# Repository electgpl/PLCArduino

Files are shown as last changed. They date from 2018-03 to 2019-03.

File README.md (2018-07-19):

# PLC Arduino NANO v1 

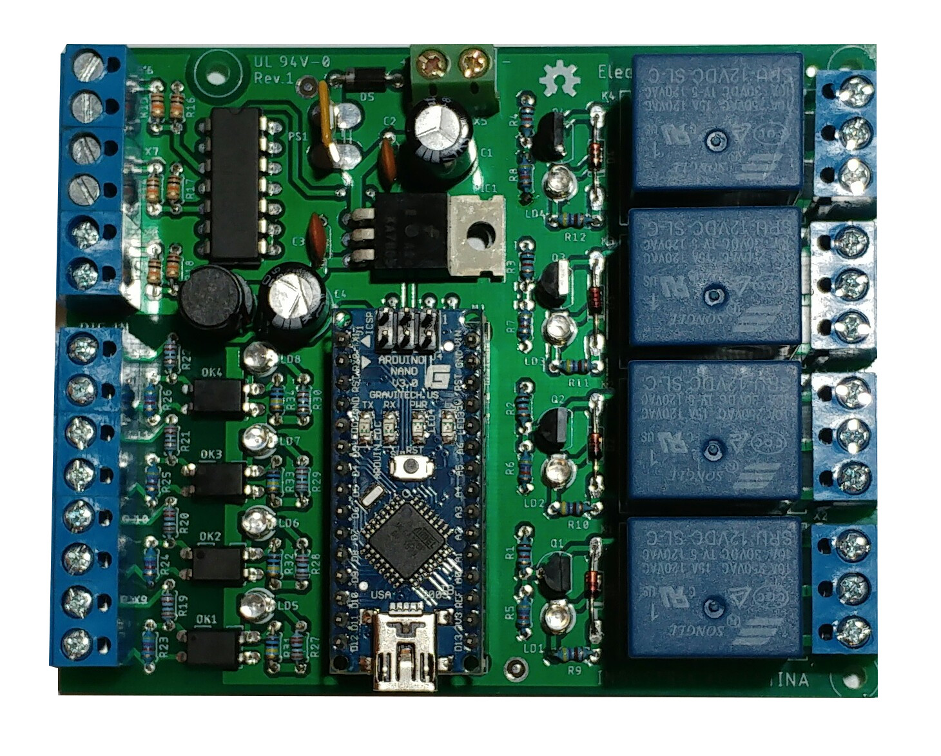
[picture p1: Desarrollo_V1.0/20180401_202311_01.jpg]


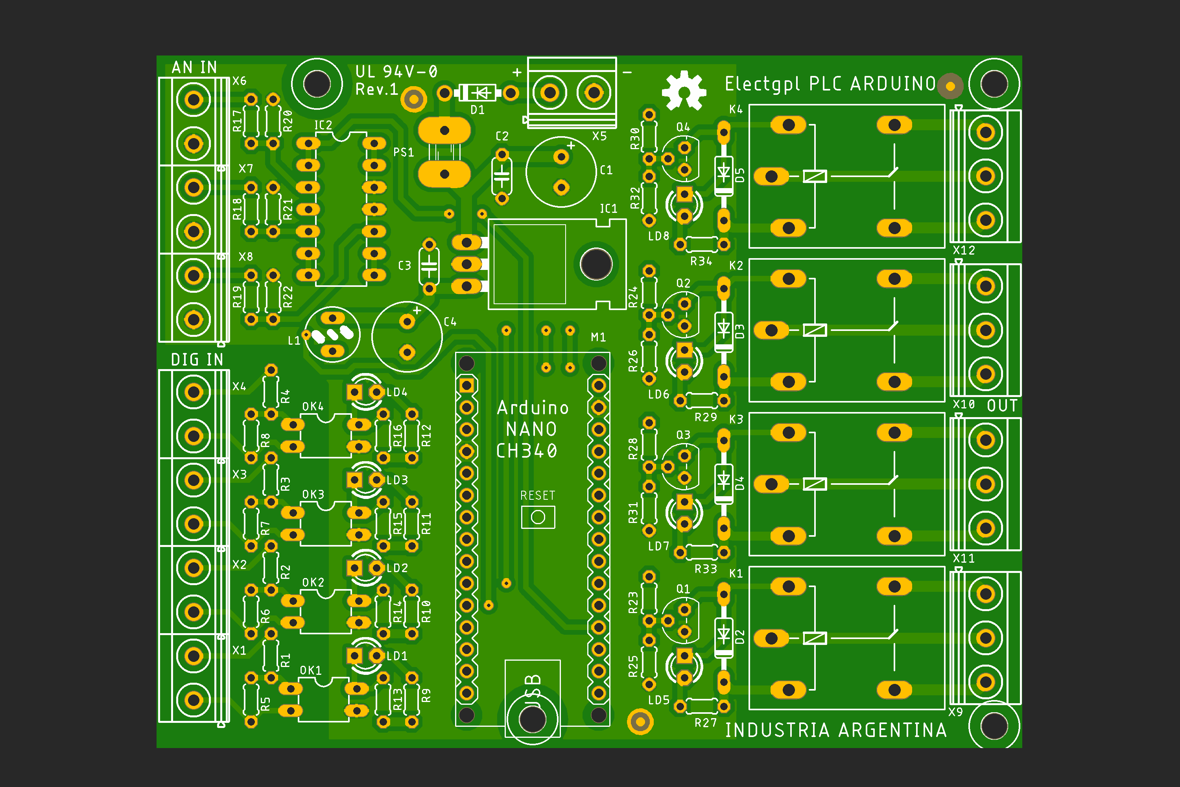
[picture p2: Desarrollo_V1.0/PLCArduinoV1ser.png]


Este es un PLC de openHard diseñado en base al microcontrolador AVR linea MEGA compatible ArduinoIDE y ArduinoNANO

  - Core AVR - **ARDUINO NANO (Versión CH340)**
  - Bootloader UART Arduino Compatible
  - USB Programming firmware
  - USB Serial Terminal/Debug
  - 4 Salidas contacto seco doble inversora 12Vdc 24Vdc 220Vac
  - 4 Entradas Digitales optoacopladas 0-10V 0-12V 0-24V 
  - 3 Entradas Analógicas Aisladas de 0-10V
  - Fuente de alimentación integrada

## Lenguajes Compatibles

  - C
  - C++
  - Basic
  - Ensamblador
  - Ladder
  - y mas...
  
## Diseño y Desarrollo

> Diseñado en dos capas con componentes THT para facilitar
> la integración al alumno, el desarrollo del PCB en el hogar y mantener
> el menor costo posible.
>                           
> PCB creado en [PCBWay].
> Diseño realizado en [Eagle].

### Instalación

Todos los archivos se encuentran disponibles en este repositorio, diagramas, pcb, etc...

### Pendientes

 - Migración del hardware AVR MEGA Compatible.
 - Incorporación de nuevos puertos de comunicación CAN, 232, 485, ethernet, BT, WiFi (Requiere un PCB de mayores dimensiones, miltilayers y tecnología SMT)
 - Mejoras en inmunidad al ruido con incorporación de componentes dedicados, MOV, TVS, PLCC, EMC, BEADS CORE
 - Mejora en la performance de la fuente utilizando un DCDC Sepic o Buck/Boost
 - Aumento de canales de entrada y salida
 - Incorporación de entrada 4-20mA

License
----

MIT

**Free Software, Hell Yeah!**

[PCBWay]: <https://www.pcbway.com/>
[Eagle]: <https://www.autodesk.com/products/eagle/overview>

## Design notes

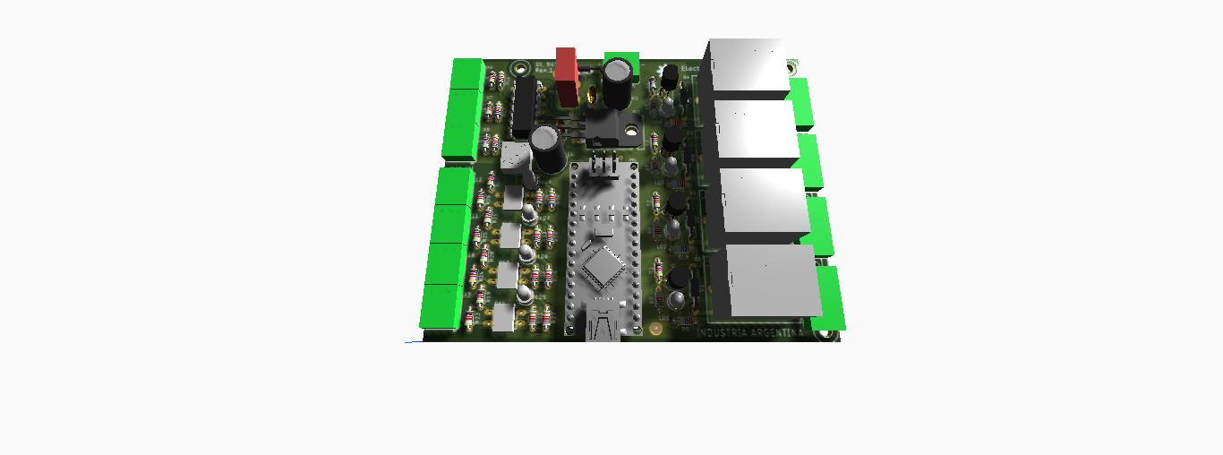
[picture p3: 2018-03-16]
Desarrollo_V1.0/PLCArduinoV1.brd1.png

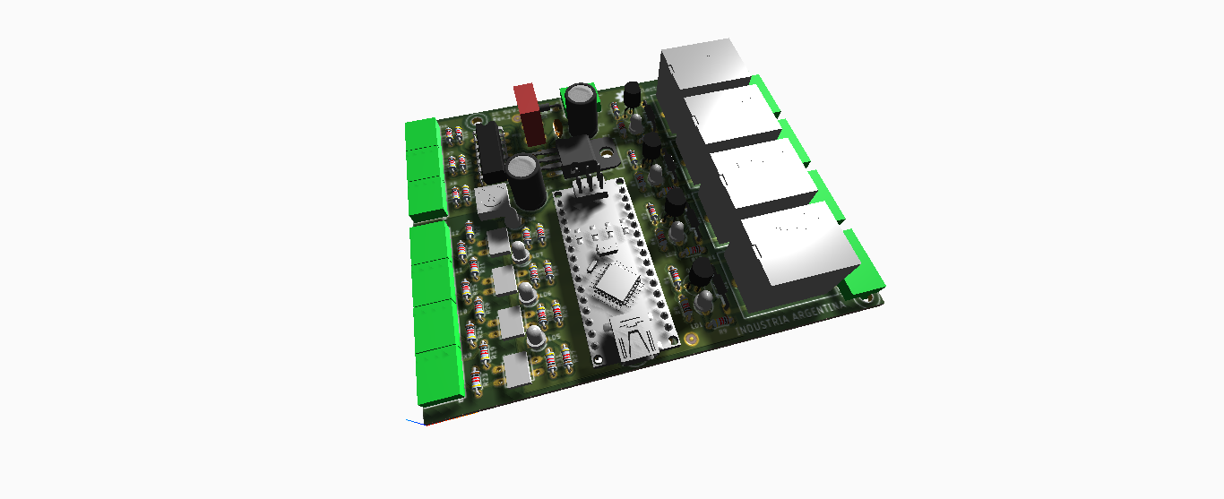
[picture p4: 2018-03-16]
Desarrollo_V1.0/PLCArduinoV1.brd2.png

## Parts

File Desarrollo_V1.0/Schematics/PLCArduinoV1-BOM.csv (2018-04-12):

Qty | Parts | Value | Package | Description
4 | R13, R14, R15, R16 | 100k | 0204/5 | RESISTOR, American symbol
3 | R20, R21, R22 | 10k | 0204/5 | RESISTOR, American symbol
4 | R23, R24, R28, R30 | 1k | 0204/5 | RESISTOR, American symbol
3 | R17, R18, R19 | 22k | 0204/5 | RESISTOR, American symbol
8 | R1, R2, R3, R4, R9, R10, R11, R12 | 2k2 | 0204/5 | RESISTOR, American symbol
4 | R27, R29, R33, R34 | 470 | 0204/5 | RESISTOR, American symbol
4 | R25, R26, R31, R32 | 47k | 0204/5 | RESISTOR, American symbol
4 | R5, R6, R7, R8 | 4k7 | 0204/5 | RESISTOR, American symbol
2 | C2, C3 | 100n | C050-024X044 | CAPACITOR, European symbol
2 | C1, C4 | 100u | E3,5-8 | POLARIZED CAPACITOR, European symbol
8 | LD1, LD2, LD3, LD4, LD5, LD6, LD7, LD8 |  | LED3MM | LED
4 | D2, D3, D4, D5 | 1N4148 | DO35-10 | DIODE
1 | D1 | 1N5819-T | DO41-7.6 | 1.0A SCHOTTKY BARRIER RECTIFIER
4 | Q1, Q2, Q3, Q4 | 2N3904 | TO92 | NPN Transistor
1 | IC1 | 7805T | TO220H | Positive VOLTAGE REGULATOR
1 | IC2 | LM324N | DIL14 | OP AMP
4 | OK1, OK2, OK3, OK4 | PC817 | DIL04 | SHARP OPTO COUPLER
1 | L1 | 82114R | 82114R | INDUCTOR
1 | PS1 | DK60 | SO5K11 | Polyswitch
4 | K1, K2, K3, K4 | G5L | G5LE | RELAY
8 | X1, X2, X3, X4, X5, X6, X7, X8 | MKDSN1,5/2-5,08 | MKDSN1,5/2-5,08 | MKDSN 1,5/ 2-5,08 Printklemme
4 | X9, X10, X11, X12 | MKDSN1,5/3-5,08 | MKDSN1,5/3-5,08 | MKDSN 1,5/ 3-5,08 Printklemme
1 | M1 | ARDUINO-NANO | ARDUINO-NANO | Arduino Nano 3.0 Bridge CH340

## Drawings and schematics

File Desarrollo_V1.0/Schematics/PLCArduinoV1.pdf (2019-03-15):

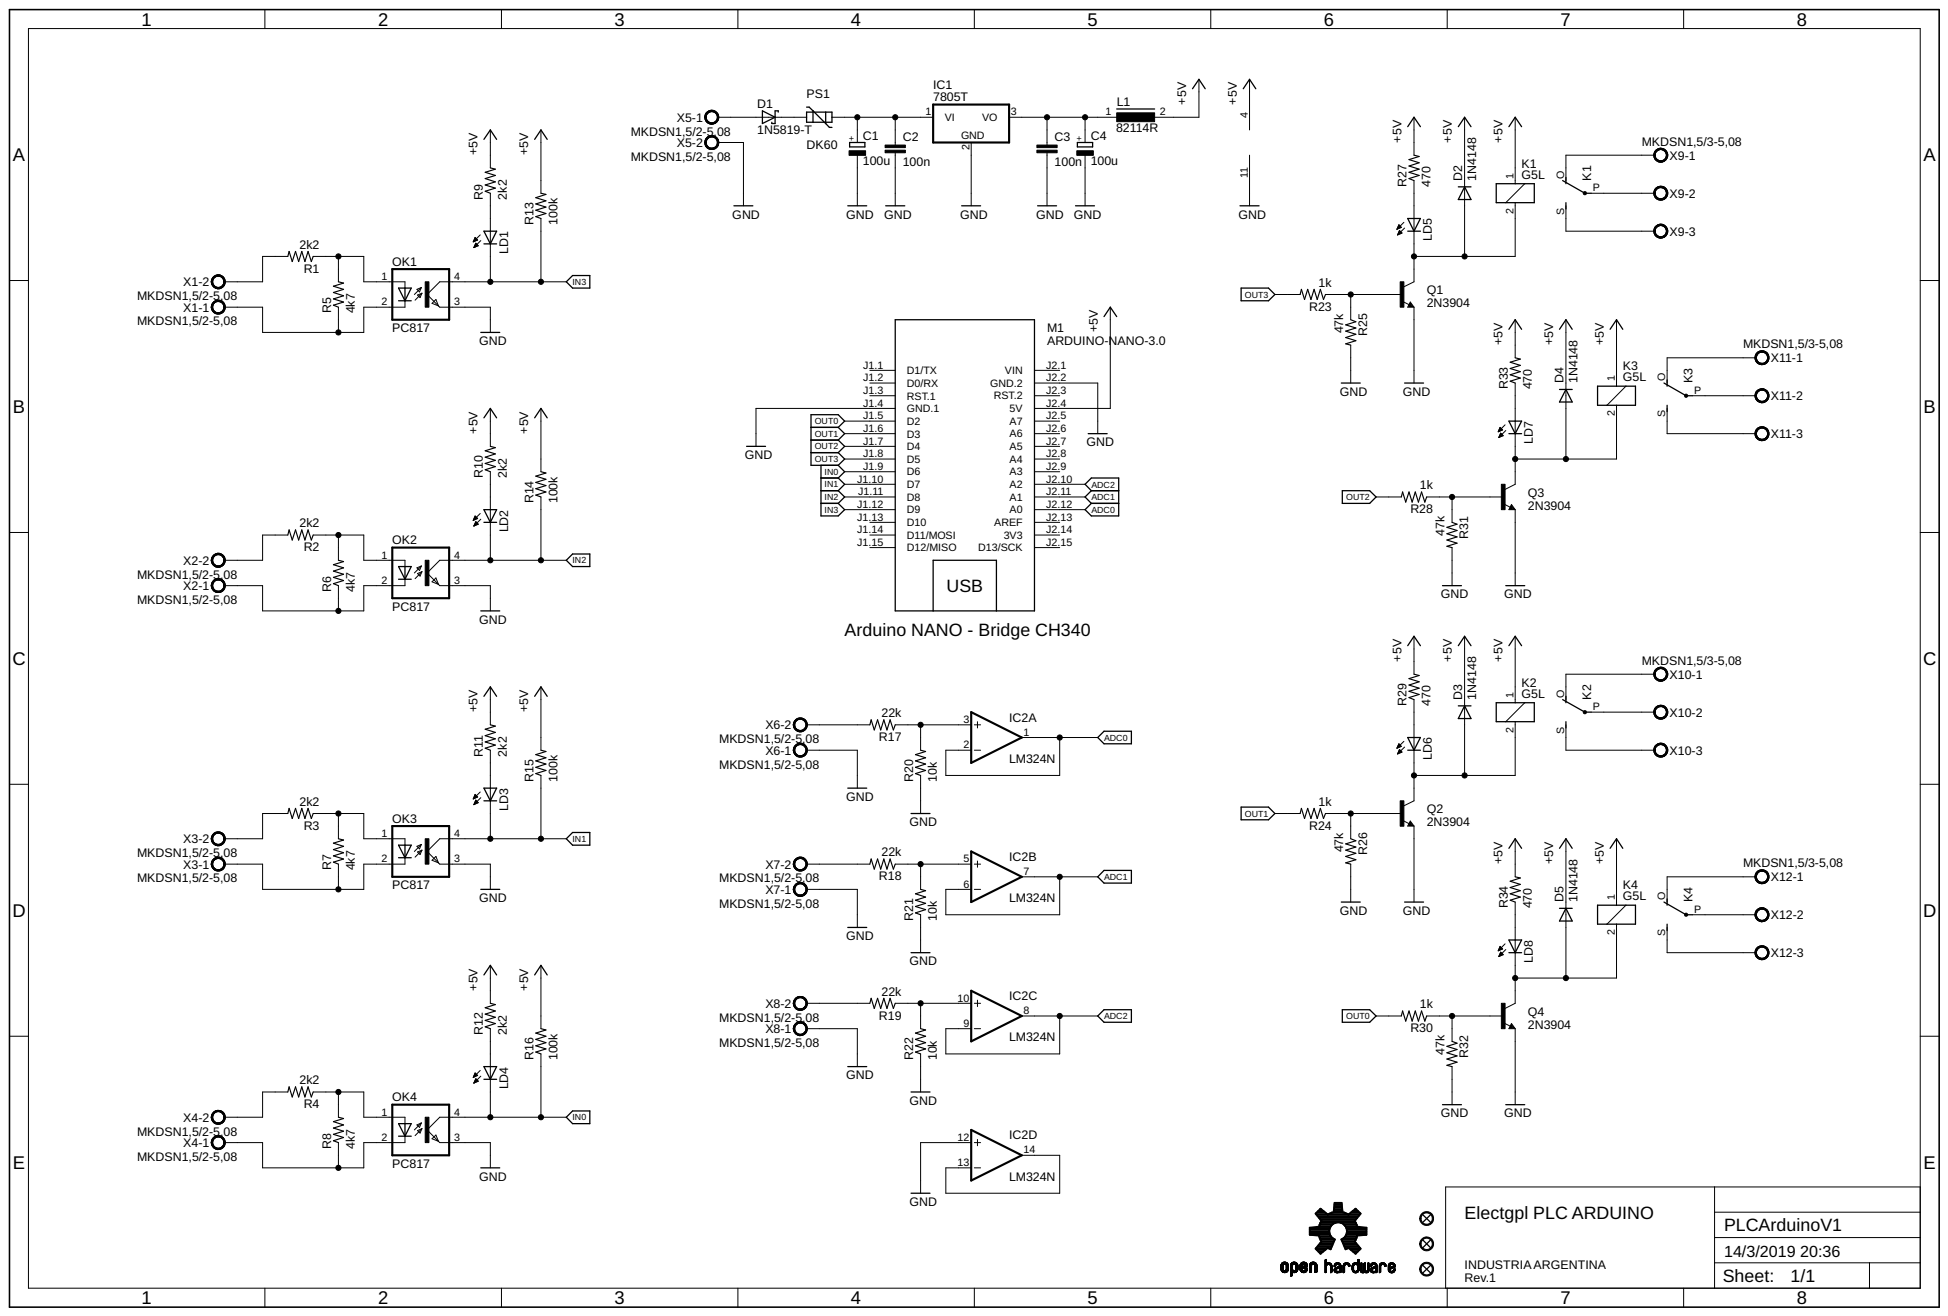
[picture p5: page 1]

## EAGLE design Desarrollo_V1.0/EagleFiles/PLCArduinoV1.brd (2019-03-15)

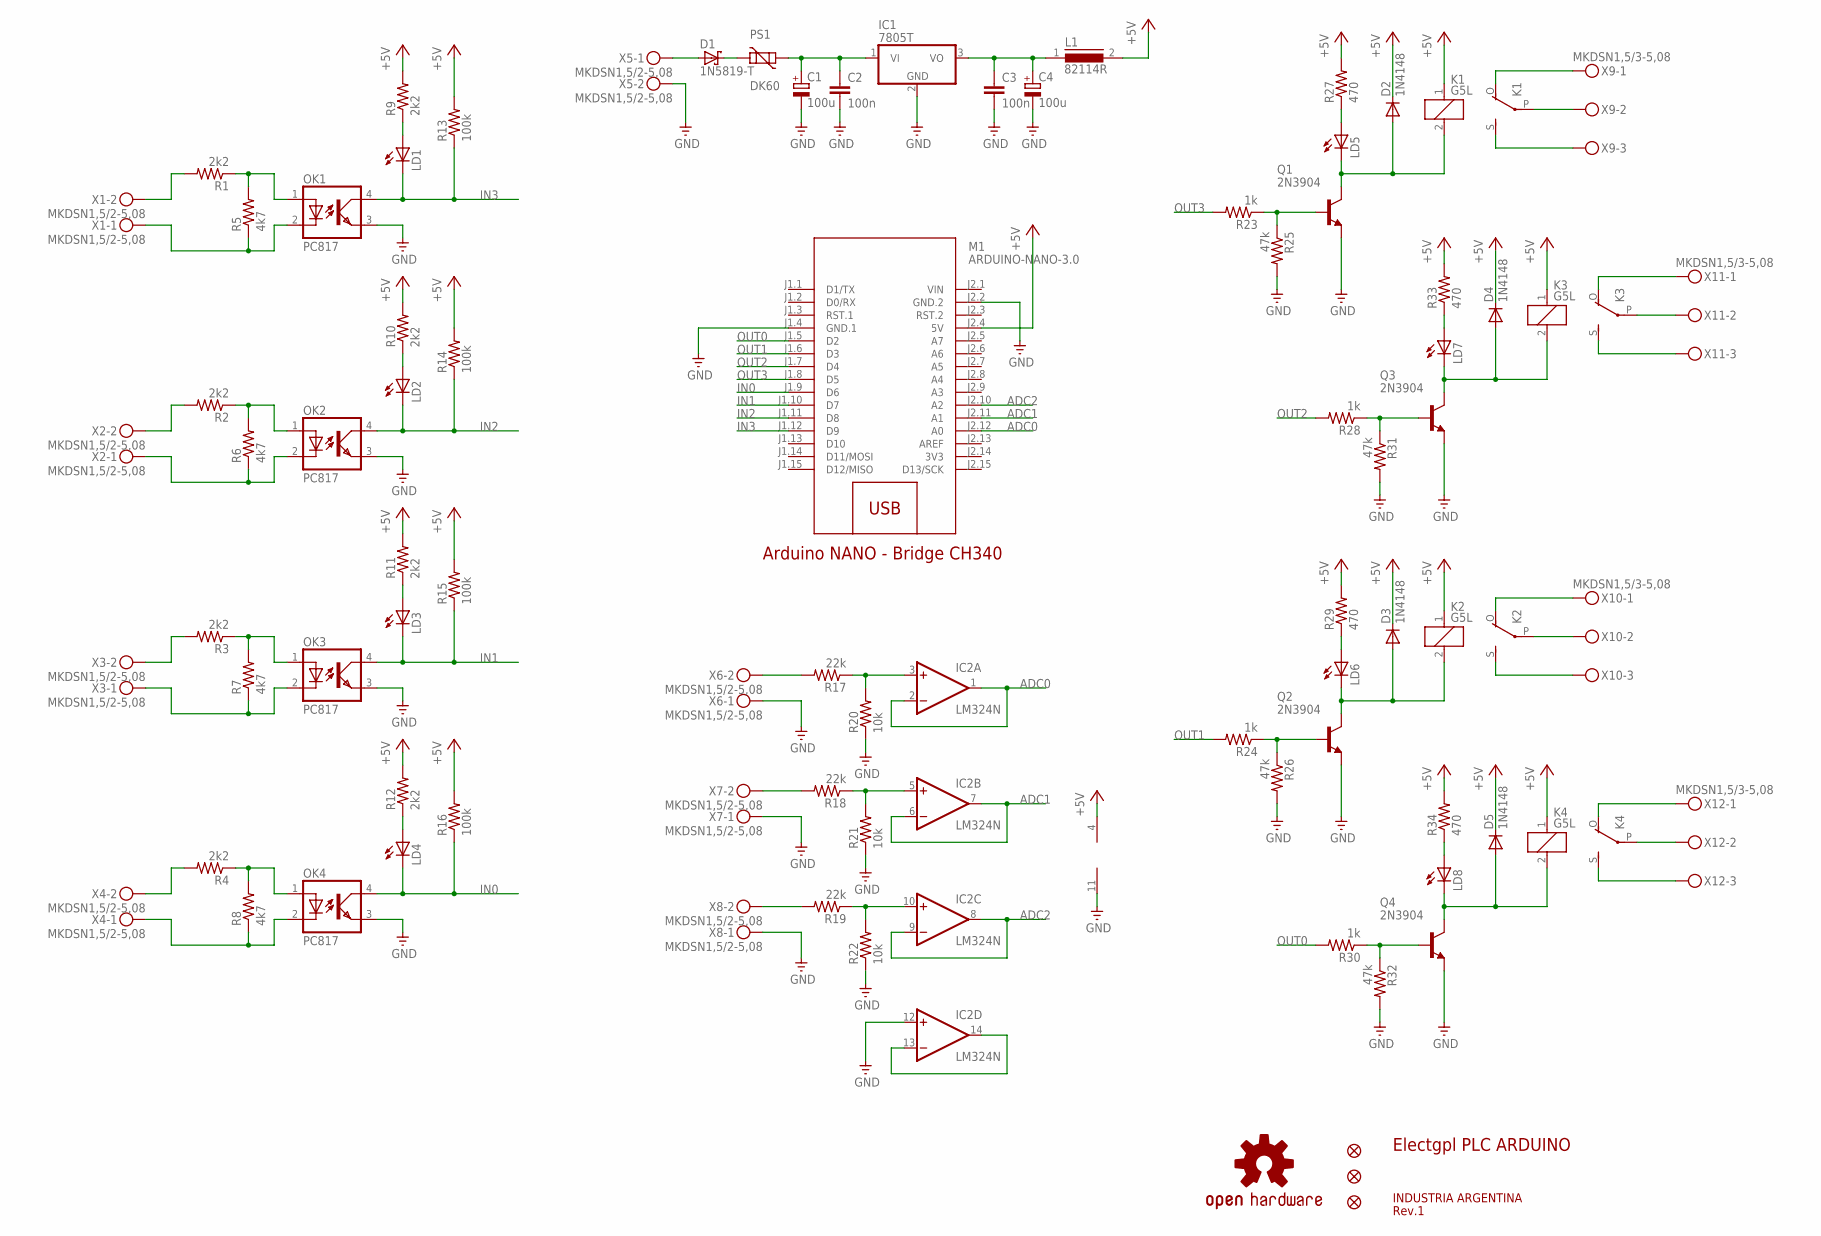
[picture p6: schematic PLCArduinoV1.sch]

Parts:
C1, C4: 100u; E3,5-8
C2, C3: 100n; C050-024X044
D1: 1N5819-T; DO41-7.6
D2, D3, D4, D5: 1N4148; DO35-10
IC1: 7805T; TO220H
IC2: LM324N; DIL14
JP1, JP2, JP3: FIDUCIAL1X2.5; FIDUCIAL-1X2.5
K1, K2, K3, K4: G5L; G5LE
L1: 82114R
LD1, LD2, LD3, LD4, LD5, LD6, LD7, LD8: LED3MM
M1: ARDUINO-NANO-3.0
OK1, OK2, OK3, OK4: PC817; DIL04
PS1: DK60; SO5K11
Q1, Q2, Q3, Q4: 2N3904; TO92
R1, R2, R3, R4, R9, R10, R11, R12: 2k2; 0204/5
R5, R6, R7, R8: 4k7; 0204/5
R13, R14, R15, R16: 100k; 0204/5
R17, R18, R19: 22k; 0204/5
R20, R21, R22: 10k; 0204/5
R23, R24, R28, R30: 1k; 0204/5
R25, R26, R31, R32: 47k; 0204/5
R27, R29, R33, R34: 470; 0204/5
U1: OSHW-LOGOM; OSHW-LOGO-M
X1, X2, X3, X4, X5, X6, X7, X8: MKDSN1,5/2-5,08
X9, X10, X11, X12: MKDSN1,5/3-5,08

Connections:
3V3: M1.J2.14 (3V3)
+5V: D2.C, D3.C, D4.C, D5.C, IC2.4 (V+), K1.1, K2.1, K3.1, K4.1, L1.2, M1.J2.4 (5V), R9.2, R10.2, R11.2, R12.2, R13.2, R14.2, R15.2, R16.2, R27.2, R29.2, R33.2, R34.2
ADC0: IC2.1 (OUT), IC2.2 (-IN), M1.J2.12 (A0)
ADC1: IC2.6 (-IN), IC2.7 (OUT), M1.J2.11 (A1)
ADC2: IC2.8 (OUT), IC2.9 (-IN), M1.J2.10 (A2)
GND: C1.-, C2.2, C3.2, C4.-, IC1.2 (GND), IC2.11 (V-), IC2.12 (+IN), M1.J1.4 (GND.1), M1.J2.2 (GND.2), OK1.3 (EMIT), OK2.3 (EMIT), OK3.3 (EMIT), OK4.3 (EMIT), Q1.3 (E), Q2.3 (E), Q3.3 (E), Q4.3 (E), R20.1, R21.1, R22.1, R25.2, R26.2, R31.2, R32.2, X5.2, X6.1, X7.1, X8.1
IN0: LD4.K (C), M1.J1.9 (D6), OK4.4 (COL), R16.1
IN1: LD3.K (C), M1.J1.10 (D7), OK3.4 (COL), R15.1
IN2: LD2.K (C), M1.J1.11 (D8), OK2.4 (COL), R14.1
IN3: LD1.K (C), M1.J1.12 (D9), OK1.4 (COL), R13.1
unnamed: LD5.A, R27.1
unnamed: D2.A, K1.2, LD5.K (C), Q1.1 (C)
unnamed: Q1.2 (B), R23.1, R25.1
unnamed: K1.P, X9.2
unnamed: K1.O, X9.1
unnamed: K1.S, X9.3
unnamed: LD7.A, R33.1
unnamed: D4.A, K3.2, LD7.K (C), Q3.1 (C)
unnamed: Q3.2 (B), R28.1, R31.1
unnamed: K3.P, X11.2
unnamed: K3.O, X11.1
unnamed: K3.S, X11.3
unnamed: LD6.A, R29.1
unnamed: D3.A, K2.2, LD6.K (C), Q2.1 (C)
unnamed: Q2.2 (B), R24.1, R26.1
unnamed: K2.P, X10.2
unnamed: K2.O, X10.1
unnamed: K2.S, X10.3
unnamed: LD8.A, R34.1
unnamed: D5.A, K4.2, LD8.K (C), Q4.1 (C)
unnamed: Q4.2 (B), R30.1, R32.1
unnamed: K4.P, X12.2
unnamed: K4.O, X12.1
unnamed: K4.S, X12.3
unnamed: OK1.1 (A), R1.1, R5.2
unnamed: OK1.2 (C), R5.1, X1.1
unnamed: R17.2, X6.2
unnamed: R18.2, X7.2
unnamed: LD1.A, R9.1
unnamed: R1.2, X1.2
unnamed: R19.2, X8.2
unnamed: OK2.1 (A), R2.1, R6.2
unnamed: OK2.2 (C), R6.1, X2.1
unnamed: LD2.A, R10.1
unnamed: R2.2, X2.2
unnamed: OK3.1 (A), R3.1, R7.2
unnamed: OK3.2 (C), R7.1, X3.1
unnamed: D1.A, X5.1
unnamed: LD3.A, R11.1
unnamed: R3.2, X3.2
unnamed: OK4.1 (A), R4.1, R8.2
unnamed: OK4.2 (C), R8.1, X4.1
unnamed: D1.C, PS1.2
unnamed: LD4.A, R12.1
unnamed: R4.2, X4.2
unnamed: C1.+, C2.1, IC1.1 (VI), PS1.1
unnamed: C3.1, C4.+, IC1.3 (VO), L1.1
unnamed: IC2.3 (+IN), R17.1, R20.2
unnamed: IC2.5 (+IN), R18.1, R21.2
unnamed: IC2.10 (+IN), R19.1, R22.2
unnamed: IC2.13 (-IN), IC2.14 (OUT)
OUT0: M1.J1.5 (D2), R30.2
OUT1: M1.J1.6 (D3), R24.2
OUT2: M1.J1.7 (D4), R28.2
OUT3: M1.J1.8 (D5), R23.2
VIN: M1.J2.1 (VIN)

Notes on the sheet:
Electgpl PLC ARDUINO
INDUSTRIA ARGENTINA
Rev.1
Arduino NANO - Bridge CH340

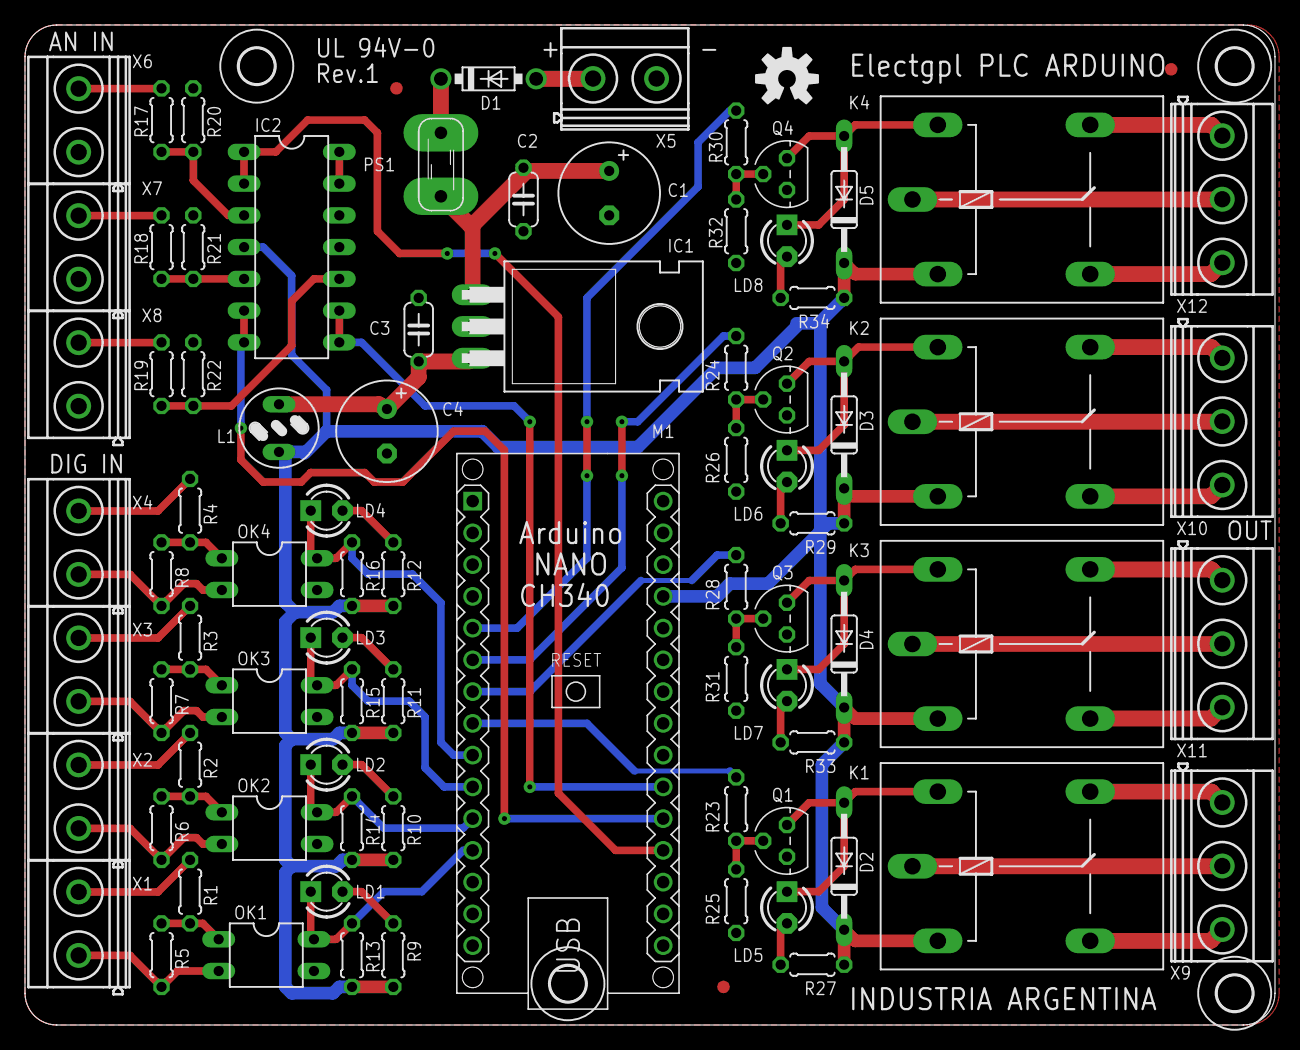
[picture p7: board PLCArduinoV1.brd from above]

Board: 2 copper layers, 100.0 x 80.0 mm, 88 parts (0 on the bottom side), 64 nets.

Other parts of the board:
U$2, U$3, U$4, U$5: 2,8

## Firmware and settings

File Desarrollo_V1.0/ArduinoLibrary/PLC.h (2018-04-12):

/* Copyright 2018, Sebastian Caccavallo
 *
 * Todos los derechos reservados.
 *
 * Este archivo es parte de la biblioteca PLC 344 rev.1.0 para Arduino.
 *
 * Redistribución y uso en formas fuente y binarias, con o sin modificación,
 * están permitidos siempre que se cumplan las siguientes condiciones:
 *
 * 1. Las redistribuciones del código fuente deben conservar el aviso de copyright 
 * anterior, esta lista de condiciones y el siguiente descargo de responsabilidad.
 *
 * 2. Las redistribuciones en formato binario deben reproducir el aviso de copyright 
 * anterior, esta lista de condiciones y la siguiente exención de responsabilidad en 
 * la documentación y / u otros materiales proporcionados con la distribución.
 *
 * 3. Ni el nombre del titular de los derechos de autor ni los nombres de sus
 * los contribuyentes pueden ser utilizados para respaldar o promocionar productos 
 * derivados de este software sin permiso escrito previo específico.
 *
 * ESTE SOFTWARE ES PROPORCIONADO POR LOS TITULARES DE LOS DERECHOS DE AUTOR Y LOS 
 * COLABORADORES "TAL CUAL" Y CUALQUIER GARANTÍA EXPRESA O IMPLÍCITA, INCLUIDAS, ENTRE OTRAS, 
 * LAS GARANTÍAS IMPLÍCITAS DE COMERCIABILIDAD E IDONEIDAD PARA UN PROPÓSITO EN PARTICULAR
 * SON RECHAZADOS. EN NINGÚN CASO SERÁ EL TITULAR DEL COPYRIGHT O LOS COLABORADORES
 * RESPONSABLE POR CUALQUIER DIRECTO, INDIRECTO, INCIDENTAL, ESPECIAL, EJEMPLAR O
 * DAÑOS CONSECUENTES (INCLUIDOS, ENTRE OTROS, LA ADQUISICIÓN DE
 * SUSTITUIR BIENES O SERVICIOS; PÉRDIDA DE USO, DATOS O GANANCIAS; O NEGOCIO
 * INTERRUPCIÓN) SIN EMBARGO Y EN CUALQUIER TEORÍA DE RESPONSABILIDAD, YA SEA EN
 * CONTRATO, RESPONSABILIDAD ESTRICTA O AGRAVIO (INCLUYENDO NEGLIGENCIA O DE OTRO TIPO)
 * QUE SURGE DE ALGUNA MANERA DEL USO DE ESTE SOFTWARE, AUN SI SE ACONSEJA
 * POSIBILIDAD DE DICHO DAÑO.
 *
 * Date: 2018-04-10 */

/*==================[inclusions]=============================================*/
#include "Arduino.h"
/*==================[macros and definitions]=================================*/
#define   Out1  2
#define   Out2  3
#define   Out3  4
#define   Out4  5

#define   In1   6
#define   In2   7
#define   In3   8
#define   In4   9

#define   An1   A0 
#define   An2   A1 
#define   An3   A2 

#define   Stat  13
/*==================[Data declaration]=======================================*/
typedef enum {
    ANALOG_IN_1 = A0,
    ANALOG_IN_2 = A1,
    ANALOG_IN_3 = A2
} PLCAnalogInput_t;

typedef enum {
    DIGITAL_IN_1 = 6,
    DIGITAL_IN_2 = 7,
    DIGITAL_IN_3 = 8,
    DIGITAL_IN_4 = 9
} PLCDigitalInput_t;

typedef enum {
    DIGITAL_OUT_1 = 2,
    DIGITAL_OUT_2 = 3,
    DIGITAL_OUT_3 = 4,
    DIGITAL_OUT_4 = 5
} PLCDigitalOutput_t;
/*==================[functions declaration]==================================*/
void PLC_Setup(void);

int PLC_ReadAnalogInputRaw(PLCAnalogInput_t input);

float PLC_ReadAnalogInputVolt(PLCAnalogInput_t input);

bool PLC_ReadContact(PLCDigitalInput_t input);

void PLC_WriteRelay(PLCDigitalOutput_t output, bool value);
/*==================[Data definition]========================================*/
/*==================[Functions definition]===================================*/

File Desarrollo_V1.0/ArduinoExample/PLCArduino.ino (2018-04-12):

#include "PLC.h"

void setup() {
  
   Serial.begin(9600);
   PLC_Setup();
   
}

void loop() {
  
   for( int i=0; i<100; i++) {
    
      if( !PLC_ReadContact(DIGITAL_IN_1) ) {
        
         PLC_WriteRelay(DIGITAL_OUT_1, true);
         PLC_WriteRelay(DIGITAL_OUT_3, false);
      }
      
      if( !PLC_ReadContact(DIGITAL_IN_3) ){
        
         PLC_WriteRelay(DIGITAL_OUT_1, false);
         PLC_WriteRelay(DIGITAL_OUT_3, true);
      }

      if( !PLC_ReadContact(DIGITAL_IN_4) ){
        
         PLC_WriteRelay(DIGITAL_OUT_2, true);
         PLC_WriteRelay(DIGITAL_OUT_4, true);
      }
      
      delay(10);
   }
   
   Serial.print("Canal Analogo 2 Volt: ");
   Serial.println( PLC_ReadAnalogInputVolt(ANALOG_IN_2) );
   
   Serial.print("Canal Analogo 2 RAW: ");
   Serial.println( PLC_ReadAnalogInputRaw(ANALOG_IN_2) );
   
   if( PLC_ReadAnalogInputVolt(ANALOG_IN_2) > 6.0 ) {
    
      Serial.println("Alarma de sobre tension mayor a 6V - APAGADO DE EMERGENCIA");
      
      PLC_WriteRelay(DIGITAL_OUT_1, false);
      PLC_WriteRelay(DIGITAL_OUT_2, false);
      PLC_WriteRelay(DIGITAL_OUT_3, false);
      PLC_WriteRelay(DIGITAL_OUT_4, false);
   }
}

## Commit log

2018-04-12 Add files via upload
    Se agregan funciones al ejemplo: Parada de Emergencia por sobre tensión
2018-04-12 Add files via upload
    Se agrega función RAW para los canales ADC. PLC_ReadAnalogInputRaw();

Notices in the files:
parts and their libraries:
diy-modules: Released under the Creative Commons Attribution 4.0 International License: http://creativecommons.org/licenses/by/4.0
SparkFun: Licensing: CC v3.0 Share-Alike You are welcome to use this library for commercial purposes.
